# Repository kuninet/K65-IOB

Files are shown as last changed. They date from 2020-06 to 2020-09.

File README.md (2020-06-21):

# 6502マイコン用 I/Oボード

## 概要
- 6502マイコンやSBC68系バスへ接続可能なI/Oボードです。
  - lite版は CPUボードのクロックが1.8432MHzとなっていることを前提としています。(PHY2(E)クロックがシリアルクロックと同じ前提)
- W65C22(VIA)やW65C51(ACIA)を搭載しています

## 回路図
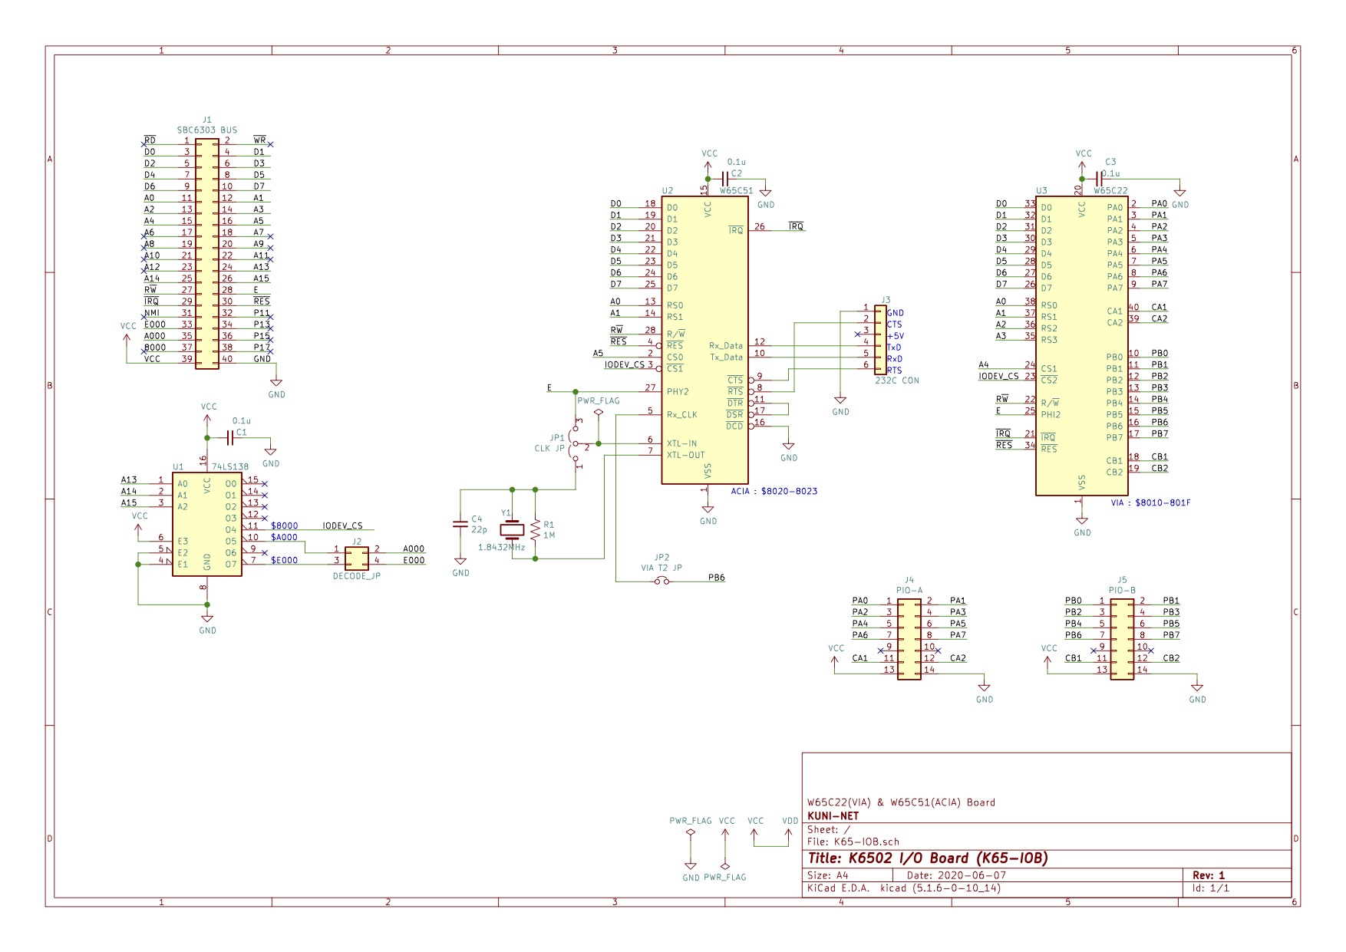
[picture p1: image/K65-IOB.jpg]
回路図


## パーツリスト
- パーツリストは[こちら](doc/partslist.md)。

## git branchの説明
- master
  - メインブランチ
- lite
  - 6502シングルボードコンピューター専用の軽量(手抜き)実装版

## 参考リンク
- 6502CPUシングルボードマイコン K65-SBC
  - https://github.com/kuninet/K65-SBC
- SBC-IO REV2
  - SBC68系I/Oボード。SBC68系バス改を装備しています。
  - https://sbc738827564.wordpress.com/2018/08/11/sbc-io-rev02/

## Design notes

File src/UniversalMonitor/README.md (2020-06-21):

# Universal Monitor W65C51対応

## 概要
- 本ボードのシリアルICとしてWDC W65C51を使用してUniversal Monitorを動かす手順をまとめます。(他の6551 ICはUniversal Monitor付属の付属のドライバーで動くはず)

## 対応方法
- 以下の手順でソースを配置・修正してください
1. devディレクトリへdev_W65C51.asmを配置
2. config.incへ追加
- config.incに本ボードのアドレスなどを定義してください。
```
USE_DEV_W65C51 = 1
	IF USE_DEV_W65C51
	;;
ACIADR:	EQU	$8020		; Data Register
ACIASR:	EQU	$8021		; Status Register
ACIACM:	EQU	$8022		; Command Register
ACIACR:	EQU	$8023		; Control Register
ACCR_V:	EQU	$1E		; Control: 8bit, 9600bps
ACCM_V:	EQU	$0B		; Command: No-parity
	ENDIF
```
3. unimon_6502.asmへドライバー読み込みを追加
- 以下のように、メインプログラムunimon_6502.asmへドライバー読み込みを追加してください。
```
	IF	USE_DEV_W65C51
	INCLUDE	"dev/dev_W65C51.asm"
	ENDIF
```
4. Makefileの修正
```
devs :=	dev/dev_6551.asm dev/dev_emily.asm dev/dev_6850.asm dev/W65C51.asm
```

## 参考
- Universal Monitor
  - https://electrelic.com/electrelic/node/1317

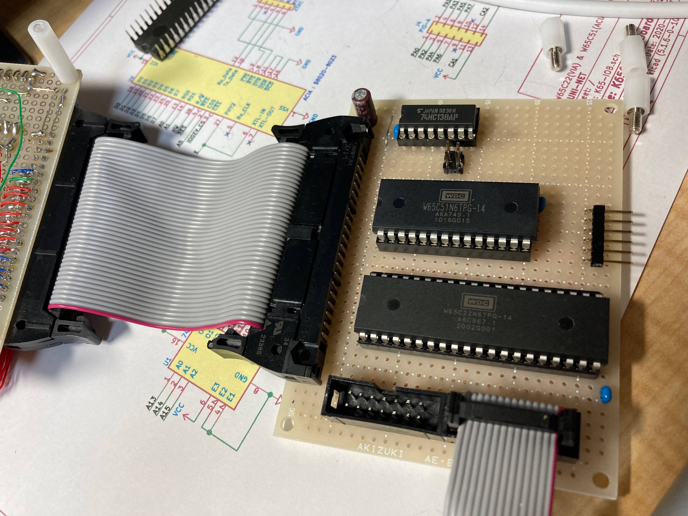
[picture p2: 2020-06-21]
image/K65-IOB-sample.jpg

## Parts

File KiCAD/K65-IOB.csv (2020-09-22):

Reference | Value | Footprint | Datasheet
U2 | W65C51 | Package_DIP:DIP-28_W15.24mm_Socket | http://www.ti.com/lit/ds/symlink/sn74ls139a.pdf
U3 | W65C22 | Package_DIP:DIP-40_W15.24mm_Socket | http://www.ti.com/lit/ds/symlink/sn74ls139a.pdf
C3 | 0.1u | Capacitor_THT:C_Disc_D3.0mm_W1.6mm_P2.50mm | ~
C4 | 0.1u | Capacitor_THT:C_Disc_D3.0mm_W1.6mm_P2.50mm | ~
J3 | PIO-A | Connector_PinHeader_2.54mm:PinHeader_2x07_P2.54mm_Vertical | ~
J4 | PIO-B | Connector_PinHeader_2.54mm:PinHeader_2x07_P2.54mm_Vertical | ~
J2 | 232C CON | Connector_PinHeader_2.54mm:PinHeader_1x06_P2.54mm_Horizontal | ~
J1 | SBC6303 BUS | Connector_PinHeader_2.54mm:PinHeader_2x20_P2.54mm_Horizontal | ~
U1 | 74LS138 | Package_DIP:DIP-16_W7.62mm_Socket | http://www.ti.com/lit/gpn/sn74LS138
C1 | 0.1u | Capacitor_THT:C_Disc_D3.0mm_W1.6mm_P2.50mm | ~
Y1 | 1.8432MHz | Crystal:Crystal_HC49-U_Vertical | ~
R1 | 1M | Resistor_THT:R_Axial_DIN0204_L3.6mm_D1.6mm_P7.62mm_Horizontal | ~
C2 | 22p | Capacitor_THT:C_Disc_D3.0mm_W1.6mm_P2.50mm | ~
JP3 | $8000 JP | Jumper:SolderJumper-3_P1.3mm_Bridged12_RoundedPad1.0x1.5mm | ~
JP1 | $A000 JP | Jumper:SolderJumper-2_P1.3mm_Open_RoundedPad1.0x1.5mm | ~
JP2 | $E000 JP | Jumper:SolderJumper-2_P1.3mm_Open_RoundedPad1.0x1.5mm | ~
JP4 | CLK JP | Jumper:SolderJumper-3_P1.3mm_Bridged12_RoundedPad1.0x1.5mm | ~
JP5 | EXT CLK JP | Jumper:SolderJumper-2_P1.3mm_Open_RoundedPad1.0x1.5mm | ~
H1 | MountingHole | MountingHole:MountingHole_3.2mm_M3 | ~
H2 | MountingHole | MountingHole:MountingHole_3.2mm_M3 | ~
H3 | MountingHole | MountingHole:MountingHole_3.2mm_M3 | ~
H4 | MountingHole | MountingHole:MountingHole_3.2mm_M3 | ~

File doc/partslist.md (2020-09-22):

# 部品リスト

|部品番号|仕様|数量|備考|
|:---:|:---|---:|:---|
|U1|74LS138|1|74HCT138でも可|
|U2|W65C51|1|ACIA シリアルIC|
|U3|W65C22|1|VIA 多用途I/O|
|C1,C3,C4|0.1uF|3|積層セラミックコンデンサ(バイパスコンデンサ)|
|C2|22pF or 33pF|1|積層セラミックコンデンサ、シリアル用クリスタルをつける場合|
|J1|2x20(40ピン) L型ボックスヘッダ|1|2列 L型ピンヘッダでも可|
|J2|2x2ピンヘッダ|1||
|J3|1x6 L型ピンヘッダ|1||
|J4、J5|2x7(14ピン)ボックスヘッダ|1|2列垂直ピンヘッダでも可|
||16ピン ICソケット|1||
||28ピン ICソケット|1||
||40ピン ICソケット|1||
|R1|1M|1|カーボン抵抗器シリアル用クリスタルを付ける場合|
|Y1|1.8432MHz|1|シリアル用クリスタルを付ける場合|

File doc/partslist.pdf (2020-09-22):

partslist.md | 2020/9/22

1 / 1

# 部品リスト

部品番
号
| 仕様 | 数
| | 量 備考
U1 | 74LS138 | 1 74HCT138でも可
U2 | W65C51 | 1 ACIA シリアルIC
U3 | W65C22 | 1 VIA 多⽤途I/O
C1,C3,C4 0.1uF | 3 積層セラミックコンデンサ(バイパスコンデンサ)
C2 | 22pF or 33pF | 1 積層セラミックコンデンサ、シリアル⽤クリスタルをつ
| | ける場合
J1 | 2x20(40ピン) L型ボックス
| ヘッダ | 1 2列 L型ピンヘッダでも可
J2 | 2x2ピンヘッダ | 1
J3 | 1x6 L型ピンヘッダ | 1
J4、J5 | 2x7(14ピン)ボックスヘッダ | 1 2列垂直ピンヘッダでも可
| 16ピン ICソケット | 1
| 28ピン ICソケット | 1
| 40ピン ICソケット | 1
R1 | 1M | 1 カーボン抵抗器シリアル⽤クリスタルを付ける場合
Y1 | 1.8432MHz | 1 シリアル⽤クリスタルを付ける場合

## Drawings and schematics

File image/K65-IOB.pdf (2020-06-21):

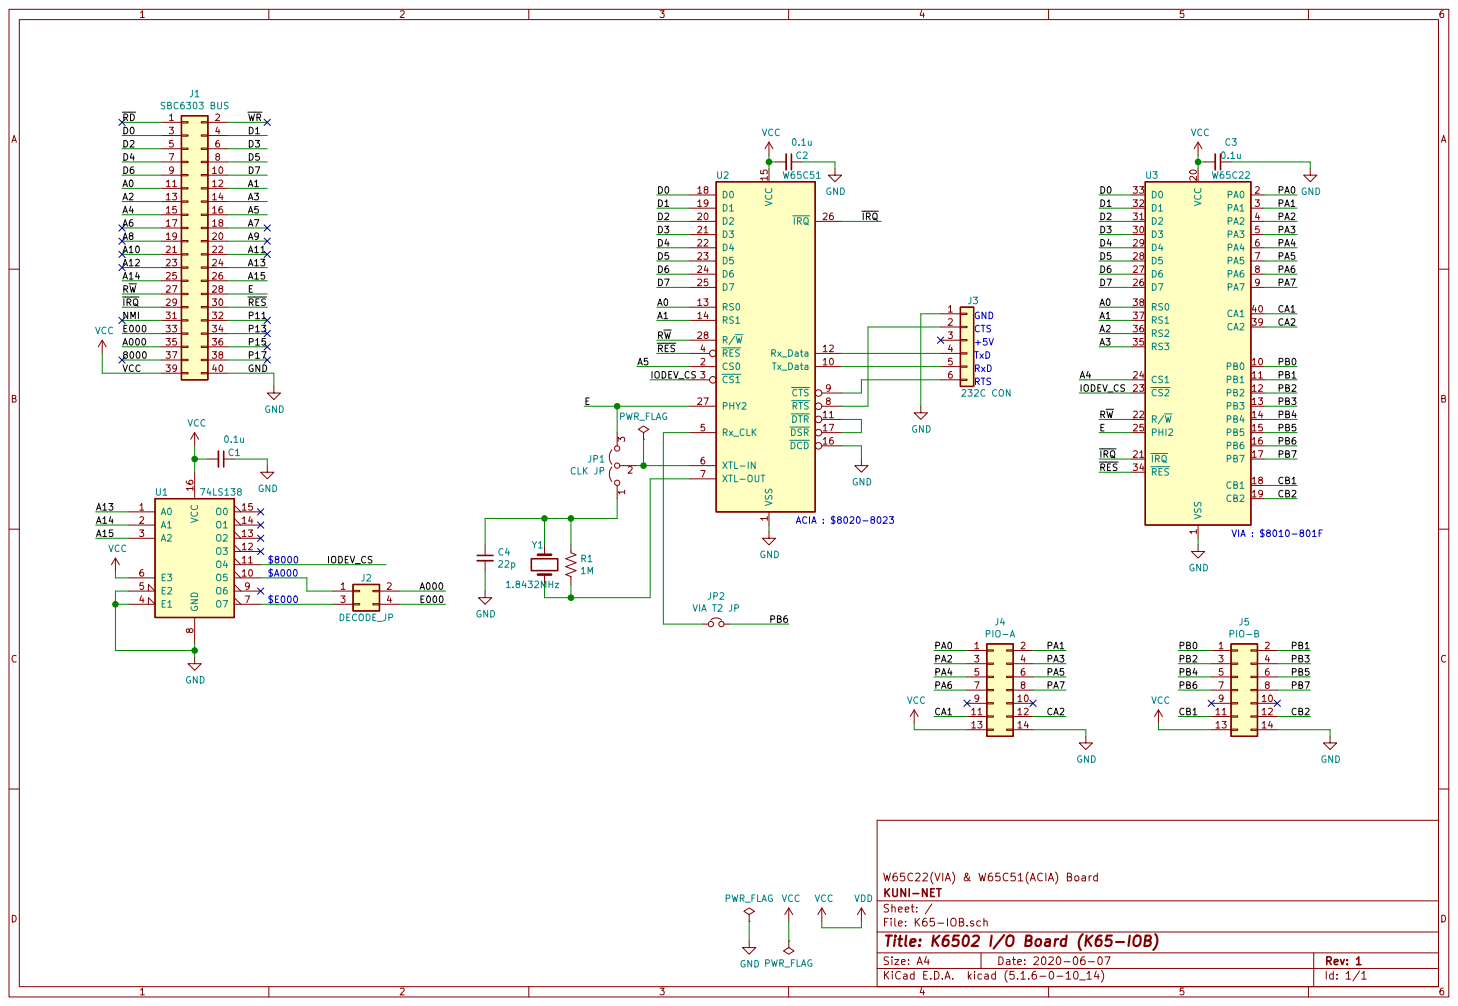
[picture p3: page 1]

1 Tx_Data 10 DTR 11 Rx_Data 12 RS0 13 RS1 14 VCC 15 DCD 16 DSR 17 D0 18 D1 19 CS0 2 D2 20 D3 21 D4 22 D5 23 D6 24 D7 25

Id: 1/1 Title: K6502 I/O Board (K65-IOB) File: K65-IOB.sch Sheet: / KUNI-NET W65C22(VIA) & W65C51(ACIA) Board GND

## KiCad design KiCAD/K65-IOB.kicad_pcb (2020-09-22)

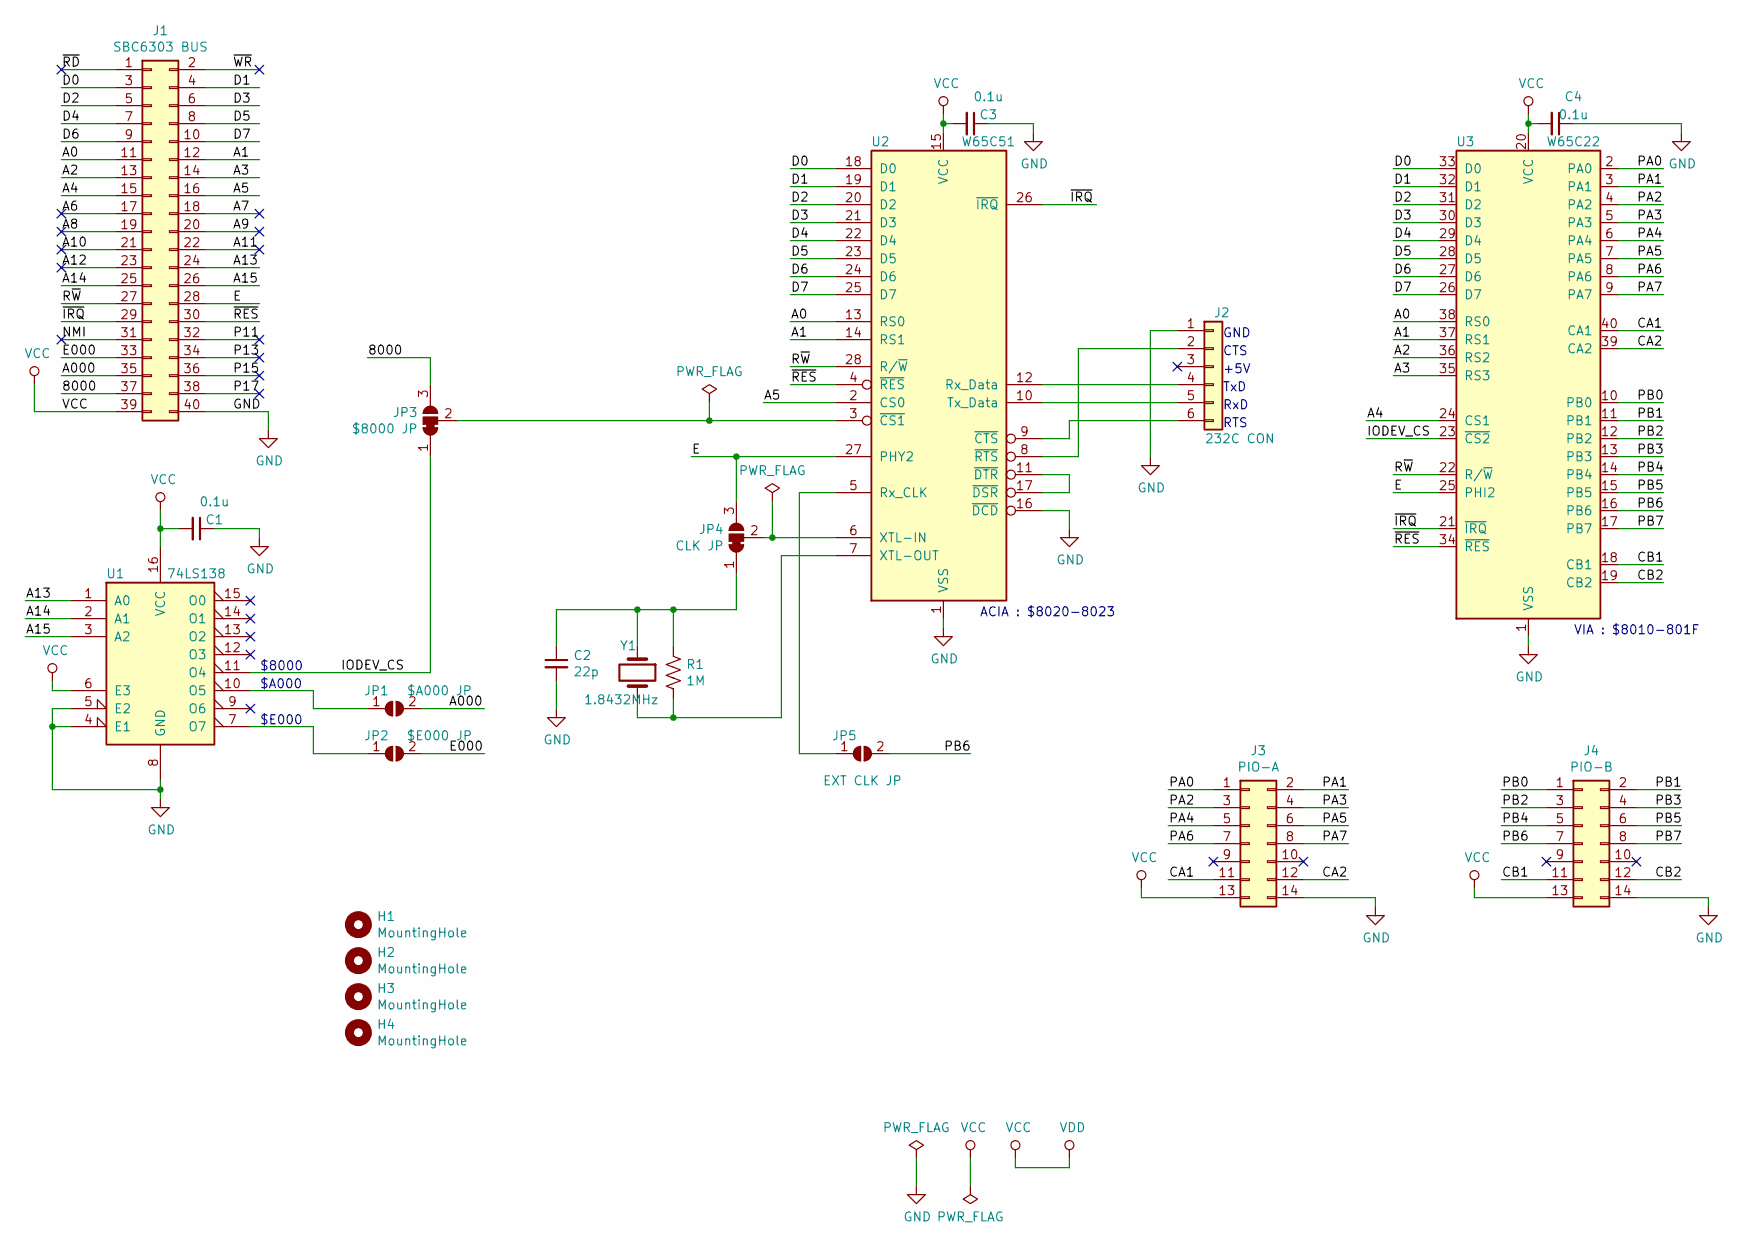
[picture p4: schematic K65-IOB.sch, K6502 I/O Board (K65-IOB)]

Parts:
C1, C3, C4: 0.1u; C_Disc_D3.0mm_W1.6mm_P2.50mm
C2: 22p; C_Disc_D3.0mm_W1.6mm_P2.50mm
H1, H2, H3, H4: MountingHole; MountingHole_3.2mm_M3
J1: SBC6303 BUS; PinHeader_2x20_P2.54mm_Horizontal
J2: 232C CON; PinHeader_1x06_P2.54mm_Horizontal
J3: PIO-A; PinHeader_2x07_P2.54mm_Vertical
J4: PIO-B; PinHeader_2x07_P2.54mm_Vertical
JP1: $A000 JP; SolderJumper-2_P1.3mm_Open_RoundedPad1.0x1.5mm
JP2: $E000 JP; SolderJumper-2_P1.3mm_Open_RoundedPad1.0x1.5mm
JP3: $8000 JP; SolderJumper-3_P1.3mm_Bridged12_RoundedPad1.0x1.5mm
JP4: CLK JP; SolderJumper-3_P1.3mm_Bridged12_RoundedPad1.0x1.5mm
JP5: EXT CLK JP; SolderJumper-2_P1.3mm_Open_RoundedPad1.0x1.5mm
R1: 1M; R_Axial_DIN0204_L3.6mm_D1.6mm_P7.62mm_Horizontal
U1: 74LS138; DIP-16_W7.62mm_Socket
U2: W65C51; DIP-28_W15.24mm_Socket
U3: W65C22; DIP-40_W15.24mm_Socket
Y1: 1.8432MHz; Crystal_HC49-U_Vertical

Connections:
/8000: J1.37, JP3.3 (B)
/A0: J1.11, U2.13 (RS0), U3.38 (RS0)
/A000: J1.35, JP1.2 (B)
/A1: J1.12, U2.14 (RS1), U3.37 (RS1)
/A2: J1.13, U3.36 (RS2)
/A3: J1.14, U3.35 (RS3)
/A4: J1.15, U3.24 (CS1)
/A5: J1.16, U2.2 (CS0)
/A6: J1.17
/A7: J1.18
/A8: J1.19
/A9: J1.20
/A10: J1.21
/A11: J1.22
/A12: J1.23
/A13: J1.24, U1.1 (A0)
/A14: J1.25, U1.2 (A1)
/A15: J1.26, U1.3 (A2)
/CA1: J3.11, U3.40 (CA1)
/CA2: J3.12, U3.39 (CA2)
/CB1: J4.11, U3.18 (CB1)
/CB2: J4.12, U3.19 (CB2)
/D0: J1.3, U2.18 (D0), U3.33 (D0)
/D1: J1.4, U2.19 (D1), U3.32 (D1)
/D2: J1.5, U2.20 (D2), U3.31 (D2)
/D3: J1.6, U2.21 (D3), U3.30 (D3)
/D4: J1.7, U2.22 (D4), U3.29 (D4)
/D5: J1.8, U2.23 (D5), U3.28 (D5)
/D6: J1.9, U2.24 (D6), U3.27 (D6)
/D7: J1.10, U2.25 (D7), U3.26 (D7)
/E: J1.28, JP4.3 (B), U2.27 (PHY2), U3.25 (PHI2)
/E000: J1.33, JP2.2 (B)
/IODEV_CS: JP3.1 (A), U1.11 (O4), U3.23 (~CS2)
/NMI: J1.31
/P11: J1.32
/P13: J1.34
/P15: J1.36
/P17: J1.38
/PA0: J3.1, U3.2 (PA0)
/PA1: J3.2, U3.3 (PA1)
/PA2: J3.3, U3.4 (PA2)
/PA3: J3.4, U3.5 (PA3)
/PA4: J3.5, U3.6 (PA4)
/PA5: J3.6, U3.7 (PA5)
/PA6: J3.7, U3.8 (PA6)
/PA7: J3.8, U3.9 (PA7)
/PB0: J4.1, U3.10 (PB0)
/PB1: J4.2, U3.11 (PB1)
/PB2: J4.3, U3.12 (PB2)
/PB3: J4.4, U3.13 (PB3)
/PB4: J4.5, U3.14 (PB4)
/PB5: J4.6, U3.15 (PB5)
/PB6: J4.7, JP5.2 (B), U3.16 (PB6)
/PB7: J4.8, U3.17 (PB7)
/R~W: J1.27, U2.28 (R/~W), U3.22 (R/~W)
/~IRQ: J1.29, U2.26 (~IRQ), U3.21 (~IRQ)
/~RD: J1.1
/~RES: J1.30, U2.4 (~RES), U3.34 (~RES)
/~WR: J1.2
GND: C1.1, C2.2, C3.1, C4.1, J1.40, J2.1, J3.14, J4.14, U1.4 (E1), U1.5 (E2), U1.8 (GND), U2.1 (VSS), U2.16 (~DCD), U3.1 (VSS)
unnamed: C2.1, JP4.1 (A), R1.1, Y1.1
unnamed: J2.2, U2.8 (~RTS)
unnamed: J2.4, U2.12 (Rx_Data)
unnamed: J2.5, U2.10 (Tx_Data)
unnamed: J2.6, U2.9 (~CTS)
unnamed: JP1.1 (A), U1.10 (O5)
unnamed: JP2.1 (A), U1.7 (O7)
unnamed: JP3.2 (C), U2.3 (~CS1)
unnamed: JP4.2 (C), U2.6 (XTL-IN)
unnamed: JP5.1 (A), U2.5 (Rx_CLK)
unnamed: R1.2, U2.7 (XTL-OUT), Y1.2
unnamed: U2.11 (~DTR), U2.17 (~DSR)
VCC: C1.2, C3.2, C4.2, J1.39, J3.13, J4.13, U1.6 (E3), U1.16 (VCC), U2.15 (VCC), U3.20 (VCC)

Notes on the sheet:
GND
CTS
+5V
TxD
RxD
RTS
$8000
$A000
$E000
ACIA : $8020-8023
VIA : $8010-801F

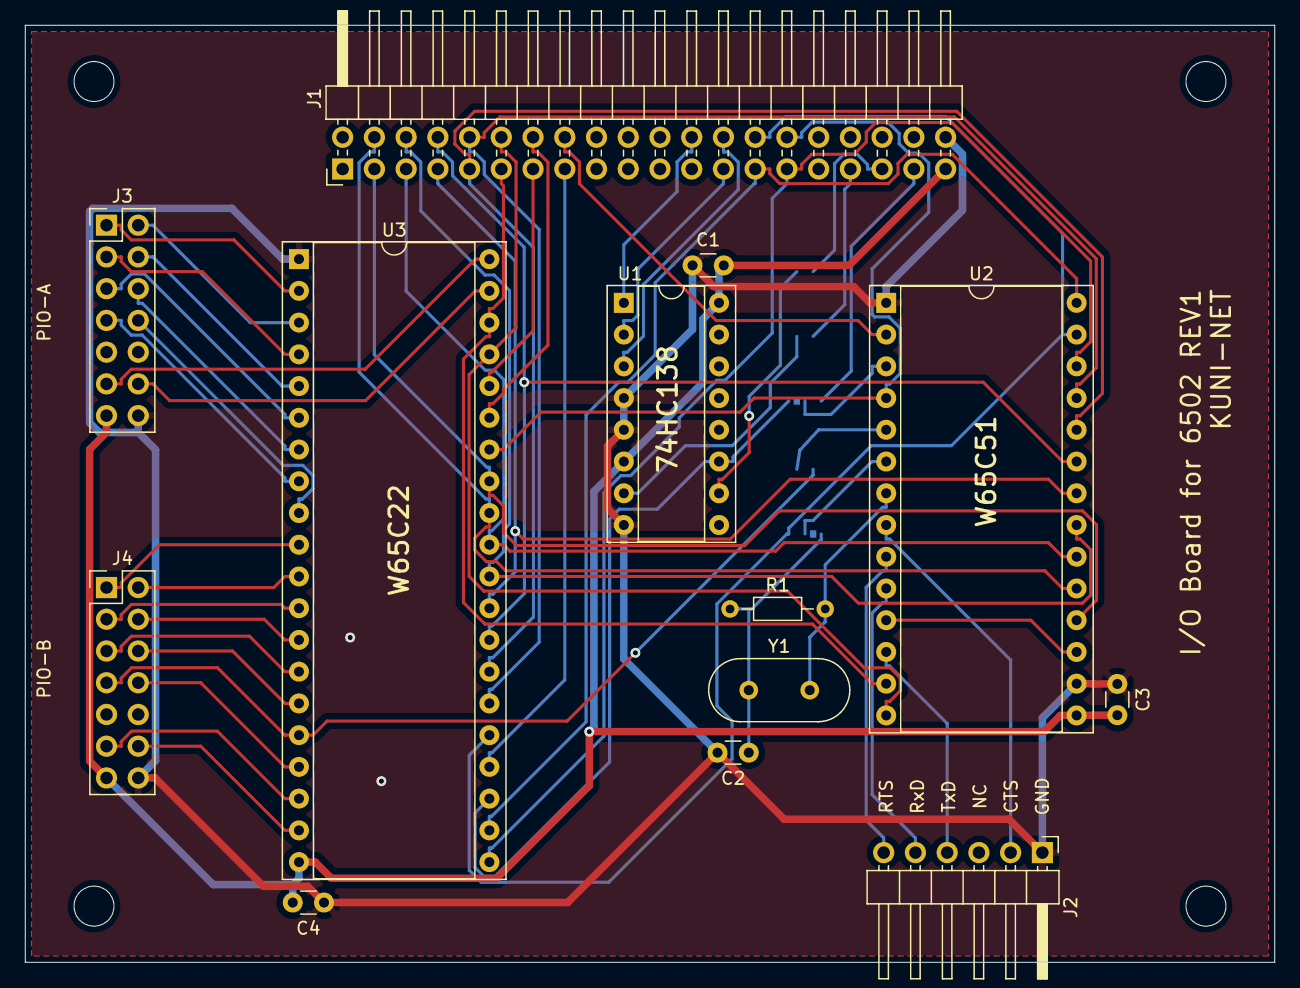
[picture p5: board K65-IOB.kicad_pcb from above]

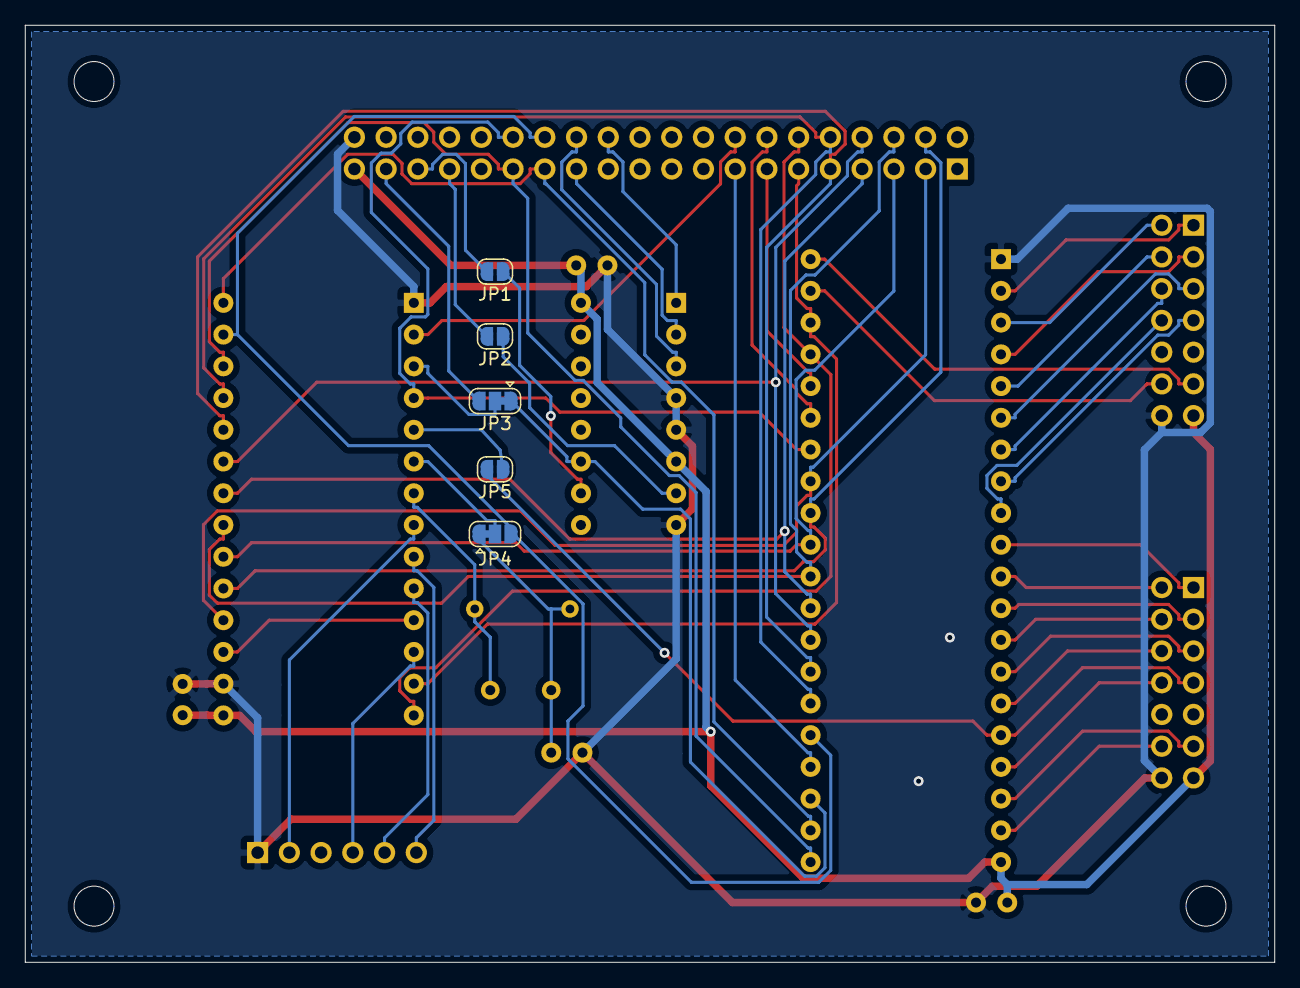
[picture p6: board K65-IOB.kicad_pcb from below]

Board: 2 copper layers, 100.0 x 75.0 mm, 22 parts (5 on the bottom side), 59 nets.

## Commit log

2020-06-08 init commit
    [K65-IOB.kicad_pcb, K65-IOB.sch]
2020-06-08 README作成
2020-06-08 README修正
2020-06-08 シンボル間違い等修正
    [K65-IOB.sch]
2020-06-21 Lite版をMasterへ統合、UniversalMonitor W65C51対応点添付
    [K65-IOB.sch]
2020-06-21 パーツリスト追加、クリスタル周波数明示
    [K65-IOB.sch]
2020-06-21 回路図 クリスタル周波数明示
2020-09-22 回路見直し、ガーバーデータ出力
    [K65-IOB.csv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]
2020-09-22 プリントパターン変更
    [K65-IOB.kicad_pcb]
